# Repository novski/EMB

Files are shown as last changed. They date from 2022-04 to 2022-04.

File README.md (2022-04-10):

# EMB

Embedded-Rack is a multi SoC Powersupply with i2c connections.
It can be used to power up to 13 Raspberry Pi's and
 one Microcontroller to monitor Powerconsumption in Rackcase.

## How to

- Get a 19 inch DIN Rack similar to this from [schroff](https://schroff.nvent.com/products/19-subracks).

- Create a Backcover like in the drawing of /powersupply 
accordingly to your powersupply. I use this [MeanWell RSP-200-5](https://www.meanwell.com/productPdf.aspx?i=437)

- Connect a Poweroutlet (with fuse) and solder it to the 
psu and the psu to the backplane with carefully chosen cable 
diameter regarding your psu. 

- Get some Backplane connectors with 24x2.54mm pinn's 
like this from [aliex](https://de.aliexpress.com/wholesale?catId=0&initiative_id=SB_20220409111809&SearchText=pcb+edge+connector).

- Solder some connectors to a daughter-card and push your SoC 
on it.
pi: [mouser](http://ch.mouser.com/Search/ProductDetail.aspx?R=M20-6102045virtualkey57420000virtualkey855-M20-6102045)

- Stick the daughter-board in to the backplane.

## Powermeasureing

The i2c connection between all SoC's can be used as plane 
communication while adding an TI INA219 can be interessting 
to measure power over a board separate. Check the adafruit 
repo's for software and the schematic for parts.

## Impressions

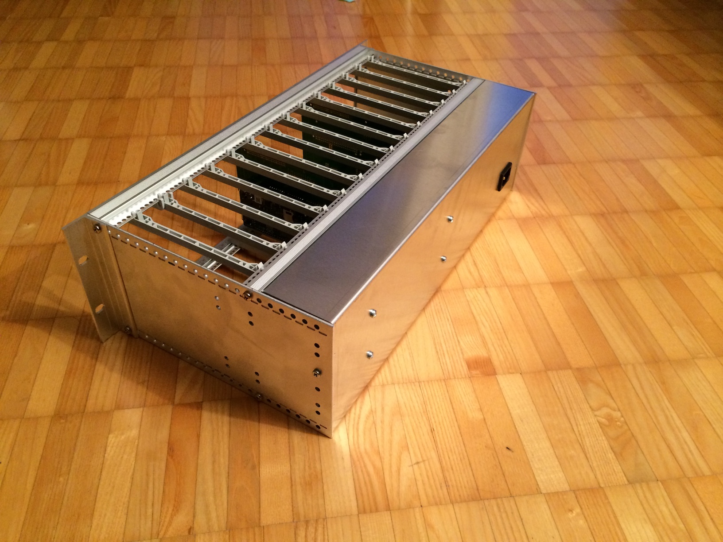
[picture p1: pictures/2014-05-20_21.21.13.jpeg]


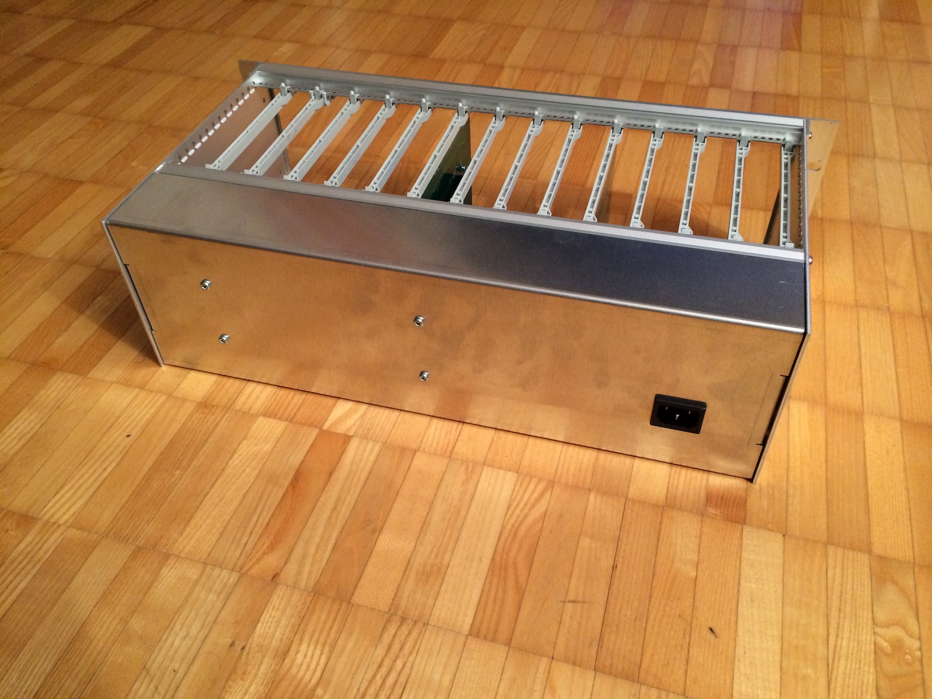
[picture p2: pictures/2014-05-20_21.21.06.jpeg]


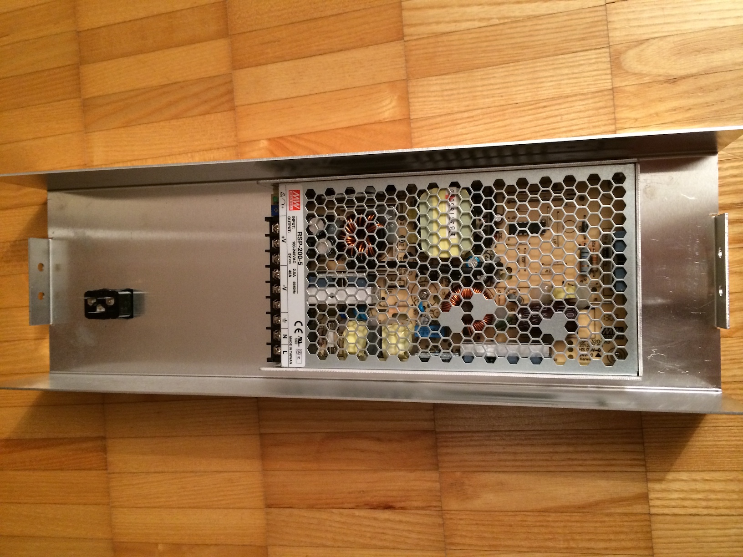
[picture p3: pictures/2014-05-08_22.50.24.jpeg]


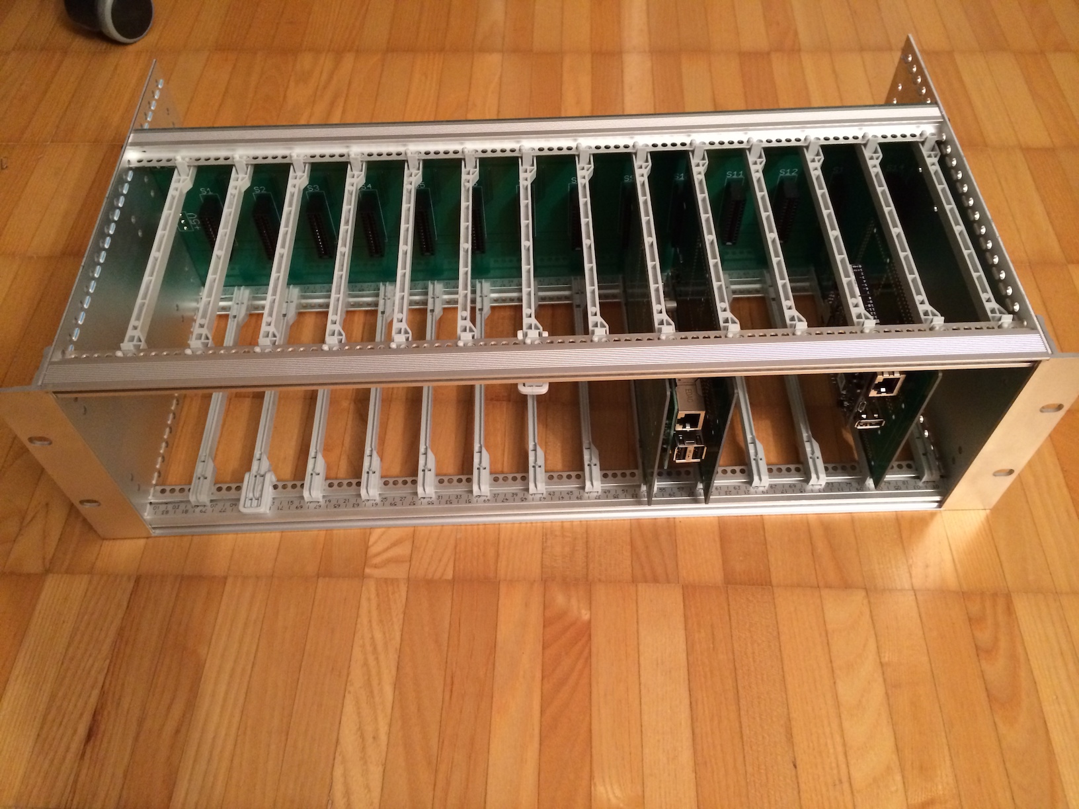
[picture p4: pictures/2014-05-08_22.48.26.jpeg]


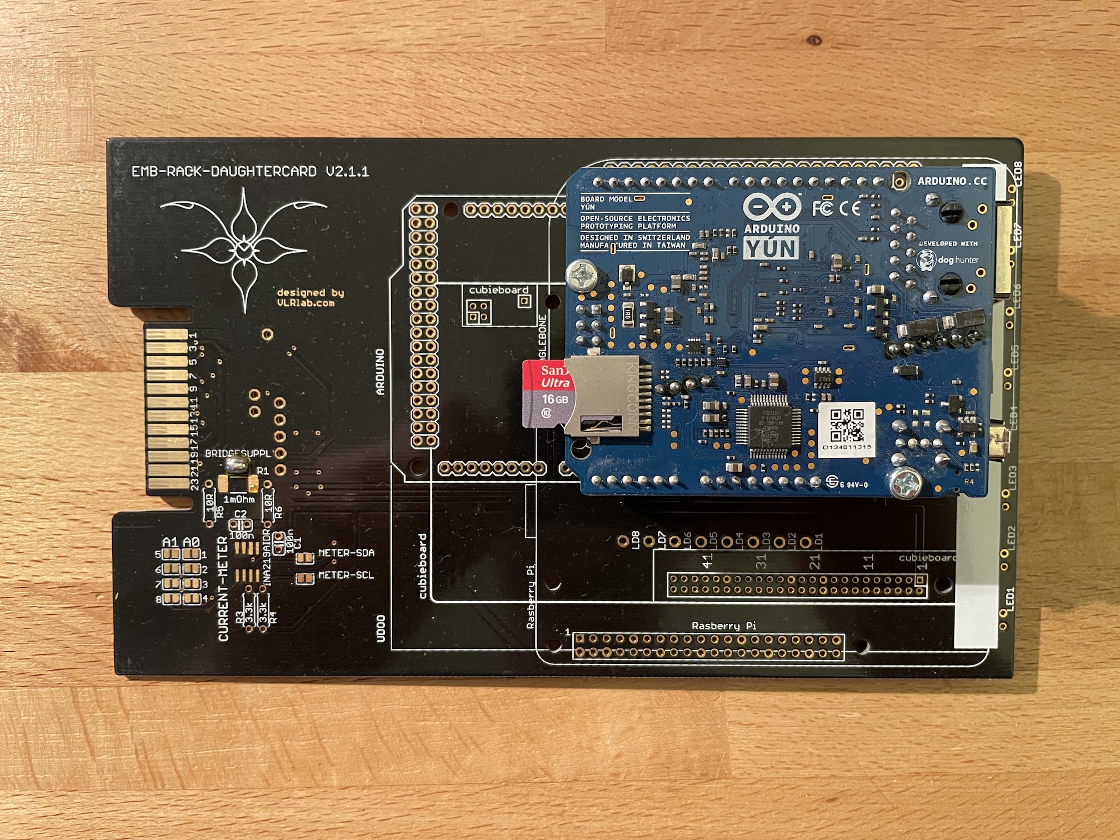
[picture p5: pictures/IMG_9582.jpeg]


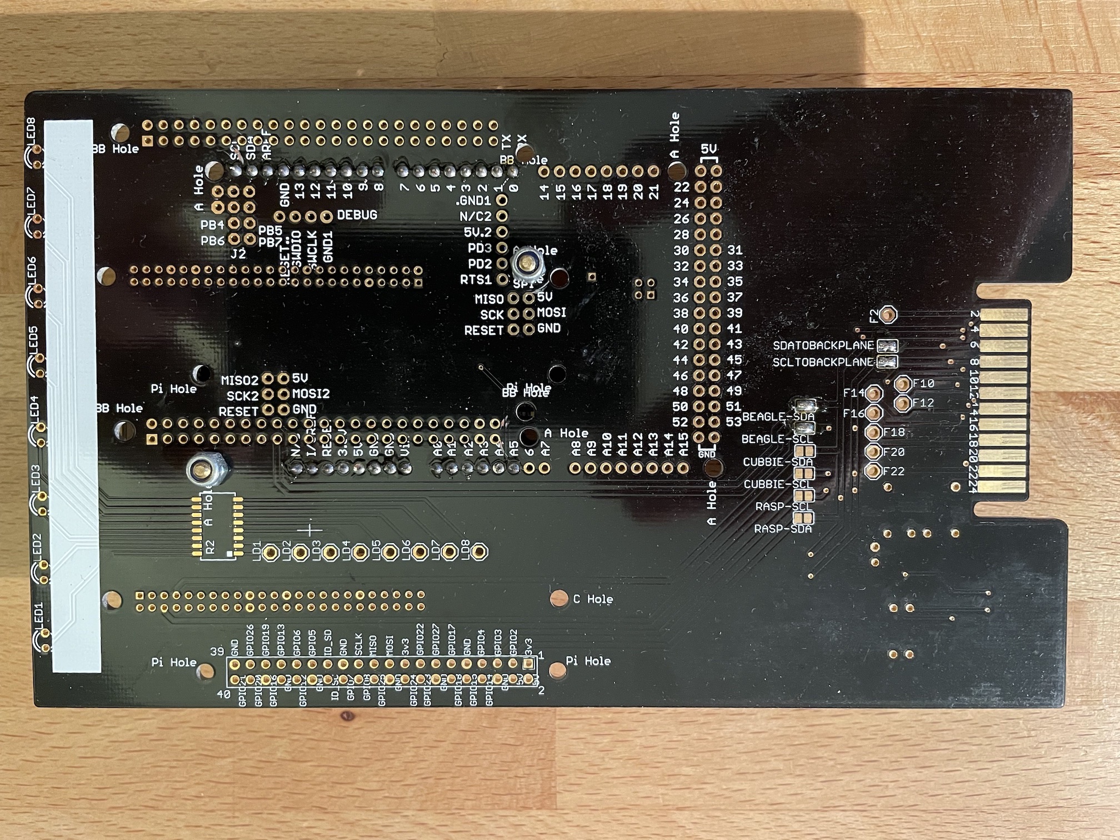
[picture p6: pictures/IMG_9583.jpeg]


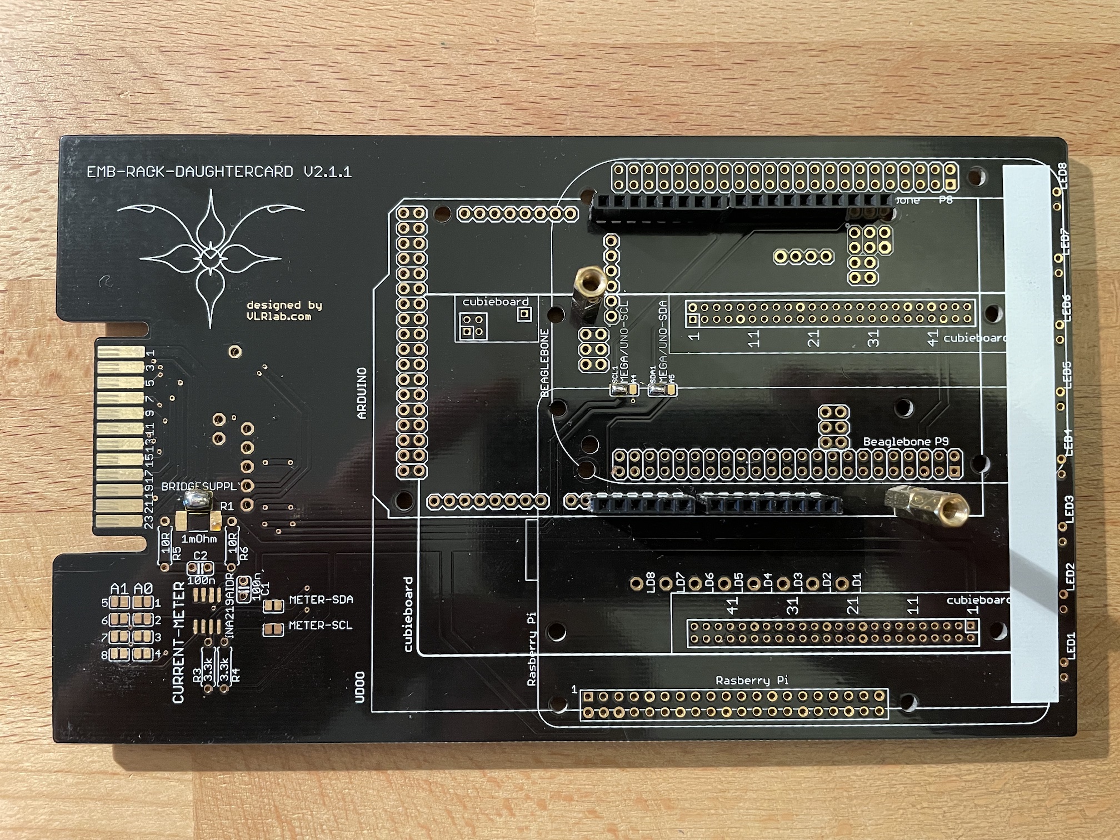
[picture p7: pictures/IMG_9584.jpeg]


## Disclaimer

All granted for free as in speech, without waranty.
(means that you can use, modify, share, sell if you like. 
But don't try to sue me for mistakes you do yourself.)
Be carefull with Power and re-calculate all wires according 
to your needs.

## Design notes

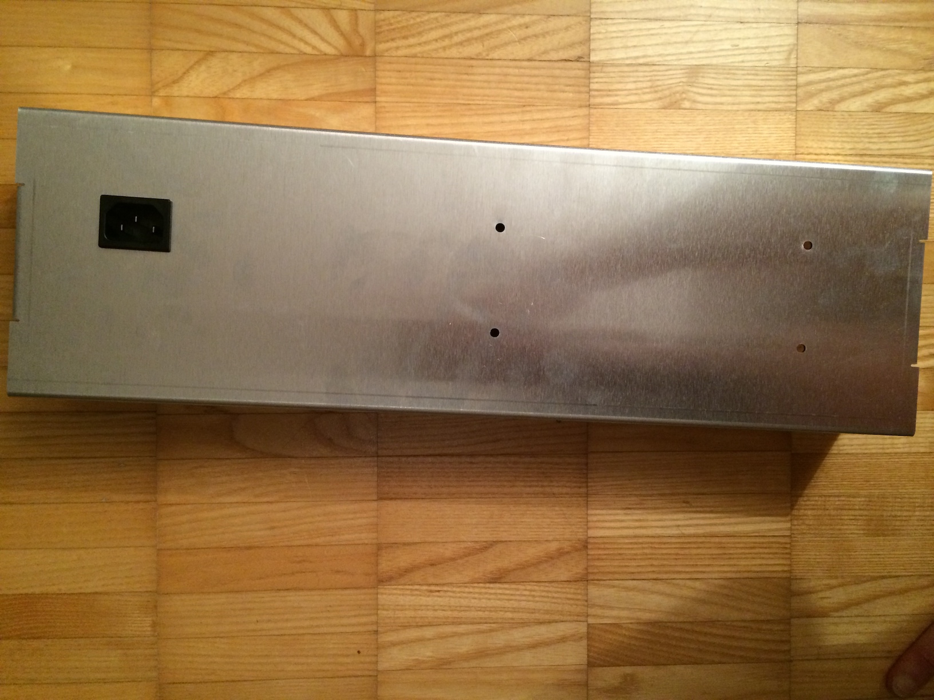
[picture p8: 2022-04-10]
pictures/2014-05-08_22.50.40.jpeg

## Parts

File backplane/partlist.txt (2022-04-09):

Partlist

Exported from 13+1 Port-Backplane.sch at 09.04.22 21:37

EAGLE Version 7.7.0 Copyright (c) 1988-2016 CadSoft

Assembly variant: 

Part     Value          Device       Package               Library    Sheet

S1       EDGECON-24P    EDGECON-24P  LEDSEE-BOARDCONN24PIN Ledsee     1
S2       EDGECON-24P    EDGECON-24P  LEDSEE-BOARDCONN24PIN Ledsee     1
S3       EDGECON-24P    EDGECON-24P  LEDSEE-BOARDCONN24PIN Ledsee     1
S4       EDGECON-24P    EDGECON-24P  LEDSEE-BOARDCONN24PIN Ledsee     1
S5       EDGECON-24P    EDGECON-24P  LEDSEE-BOARDCONN24PIN Ledsee     1
S6       EDGECON-24P    EDGECON-24P  LEDSEE-BOARDCONN24PIN Ledsee     1
S7       EDGECON-24P    EDGECON-24P  LEDSEE-BOARDCONN24PIN Ledsee     1
S8       EDGECON-24P    EDGECON-24P  LEDSEE-BOARDCONN24PIN Ledsee     1
S9       EDGECON-24P    EDGECON-24P  LEDSEE-BOARDCONN24PIN Ledsee     1
S10      EDGECON-24P    EDGECON-24P  LEDSEE-BOARDCONN24PIN Ledsee     1
S11      EDGECON-24P    EDGECON-24P  LEDSEE-BOARDCONN24PIN Ledsee     1
S12      EDGECON-24P    EDGECON-24P  LEDSEE-BOARDCONN24PIN Ledsee     1
S13      EDGECON-24P    EDGECON-24P  LEDSEE-BOARDCONN24PIN Ledsee     1
S14      EDGECON-24P    EDGECON-24P  LEDSEE-BOARDCONN24PIN Ledsee     1
U$6      SOLPAD-1,6MM   SOLPAD-1,6MM SOLDERPAD1.5MM        holes_Ivan 1
U$7      SOLPAD-1,6MM   SOLPAD-1,6MM SOLDERPAD1.5MM        holes_Ivan 1
U$8      SOLPAD-1,6MM   SOLPAD-1,6MM SOLDERPAD1.5MM        holes_Ivan 1
U$9      SOLPAD-1,6MM   SOLPAD-1,6MM SOLDERPAD1.5MM        holes_Ivan 1
U$10     SOLPAD-1,6MM   SOLPAD-1,6MM SOLDERPAD1.5MM        holes_Ivan 1
U$11     SOLPAD-1,6MM   SOLPAD-1,6MM SOLDERPAD1.5MM        holes_Ivan 1

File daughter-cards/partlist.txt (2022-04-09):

Partlist

Exported from UniversalRackcard.sch at 09.04.22 21:35

EAGLE Version 7.7.0 Copyright (c) 1988-2016 CadSoft

Assembly variant: 

Part           Value            Device           Package         Library               Sheet

1              GND              SJ               SJ              jumper                1
2              VDD              SJ               SJ              jumper                1
3              SDA              SJ               SJ              jumper                1
4              SCL              SJ               SJ              jumper                1
5              GND              SJ               SJ              jumper                1
6              VDD              SJ               SJ              jumper                1
7              SDA              SJ               SJ              jumper                1
8              SCL              SJ               SJ              jumper                1
BEAGLE-SCL                      SJ               SJ              jumper                1
BEAGLE-SDA                      SJ               SJ              jumper                1
BRIDGESUPPLY                    SJW              SJW             jumper                1
C1             100n             C-EU025-024X044  C025-024X044    rcl                   1
C2             100n             C-EU025-024X044  C025-024X044    rcl                   1
CUBBIE-SCL                      SJ               SJ              jumper                1
CUBBIE-SDA                      SJ               SJ              jumper                1
CURRENT-METER  INA219AIDR       INA219AIDR       SO-08           texas                 1
F2             SE13             SE13             SE13            solpad                1
F10            SE13             SE13             SE13            solpad                1
F12            SE13             SE13             SE13            solpad                1
F14            SE13             SE13             SE13            solpad                1
F16            SE13             SE13             SE13            solpad                1
F18            SE13             SE13             SE13            solpad                1
F20            SE13             SE13             SE13            solpad                1
F22            SE13             SE13             SE13            solpad                1
LD1            SE13             SE13             SE13            solpad                1
LD2            SE13             SE13             SE13            solpad                1
LD3            SE13             SE13             SE13            solpad                1
LD4            SE13             SE13             SE13            solpad                1
LD5            SE13             SE13             SE13            solpad                1
LD6            SE13             SE13             SE13            solpad                1
LD7            SE13             SE13             SE13            solpad                1
LD8            SE13             SE13             SE13            solpad                1
LED1                            LED3MM           LED3MM          led                   1
LED2                            LED3MM           LED3MM          led                   1
LED3                            LED3MM           LED3MM          led                   1
LED4                            LED3MM           LED3MM          led                   1
LED5                            LED3MM           LED3MM          led                   1
LED6                            LED3MM           LED3MM          led                   1
LED7                            LED3MM           LED3MM          led                   1
LED8                            LED3MM           LED3MM          led                   1
MEGA/UNO-SCL                    SJ2W             SJ_2            jumper                1
MEGA/UNO-SDA                    SJ2W             SJ_2            jumper                1
METER-SCL                       SJ               SJ              jumper                1
METER-SDA                       SJ               SJ              jumper                1
R1             1mOhm            R-EU_R2512       R2512           resistor              1
R2                              4816P-1SOIC16W   SOIC16W         Bourns Resistor Array 1
R3             3.3k             R-EU_0207/7      0207/7          rcl                   1
R4             3.3k             R-EU_0207/7      0207/7          rcl                   1
R5             10R              R-EU_0207/7      0207/7          rcl                   1
R6             10R              R-EU_0207/7      0207/7          rcl                   1
RASP-SCL                        SJ               SJ              jumper                1
RASP-SDA                        SJ               SJ              jumper                1
SCLTOBACKPLANE                  SJ               SJ              jumper                1
SDATOBACKPLANE                  SJ               SJ              jumper                1
U$2            VLR_EUROCARD     VLR_EUROCARD     VLR_EUROCARD    Frames_VLR            1
U$4            ARDUINO_ALL      ARDUINO_ALL      ALL             Arduino               1
U$5            CUBIEBOARD       CUBIEBOARD       CUBIEBOARD      Cubie                 1
U$6            BEAGLEBONE-BLACK BEAGLEBONE-BLACK BEAGLEBONE      beaglebone            1
U$7            RASPBERRY-PI_B+  RASPBERRY-PI_B+  RASPBERRY-PI_B+ RaspberryPi           1

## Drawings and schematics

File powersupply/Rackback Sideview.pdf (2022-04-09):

B

C

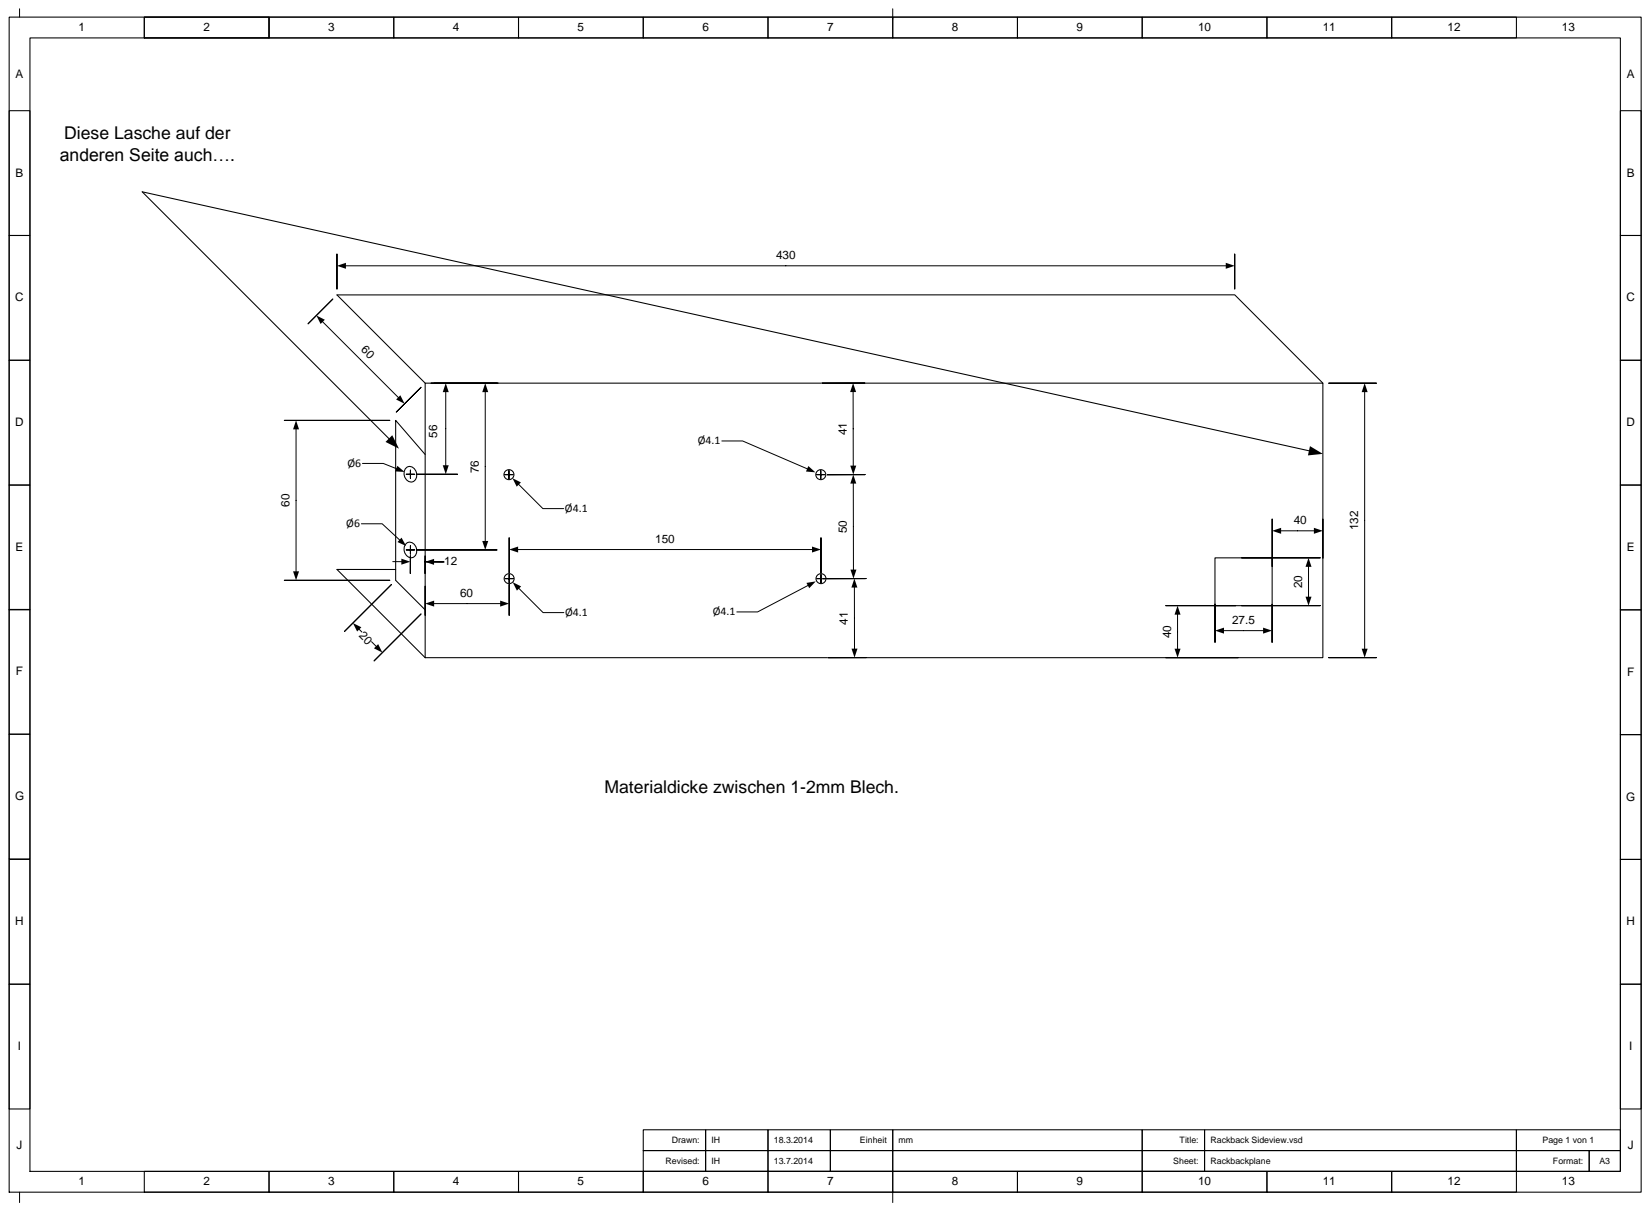
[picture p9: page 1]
Rackback Sideview.vsd Rackbackplane; Format:; A3 Title:; Sheet: Drawn:; Page 1 von 1 Revised:; Einheit

Diese Lasche auf der
anderen Seite auch….

Materialdicke zwischen 1-2mm Blech.

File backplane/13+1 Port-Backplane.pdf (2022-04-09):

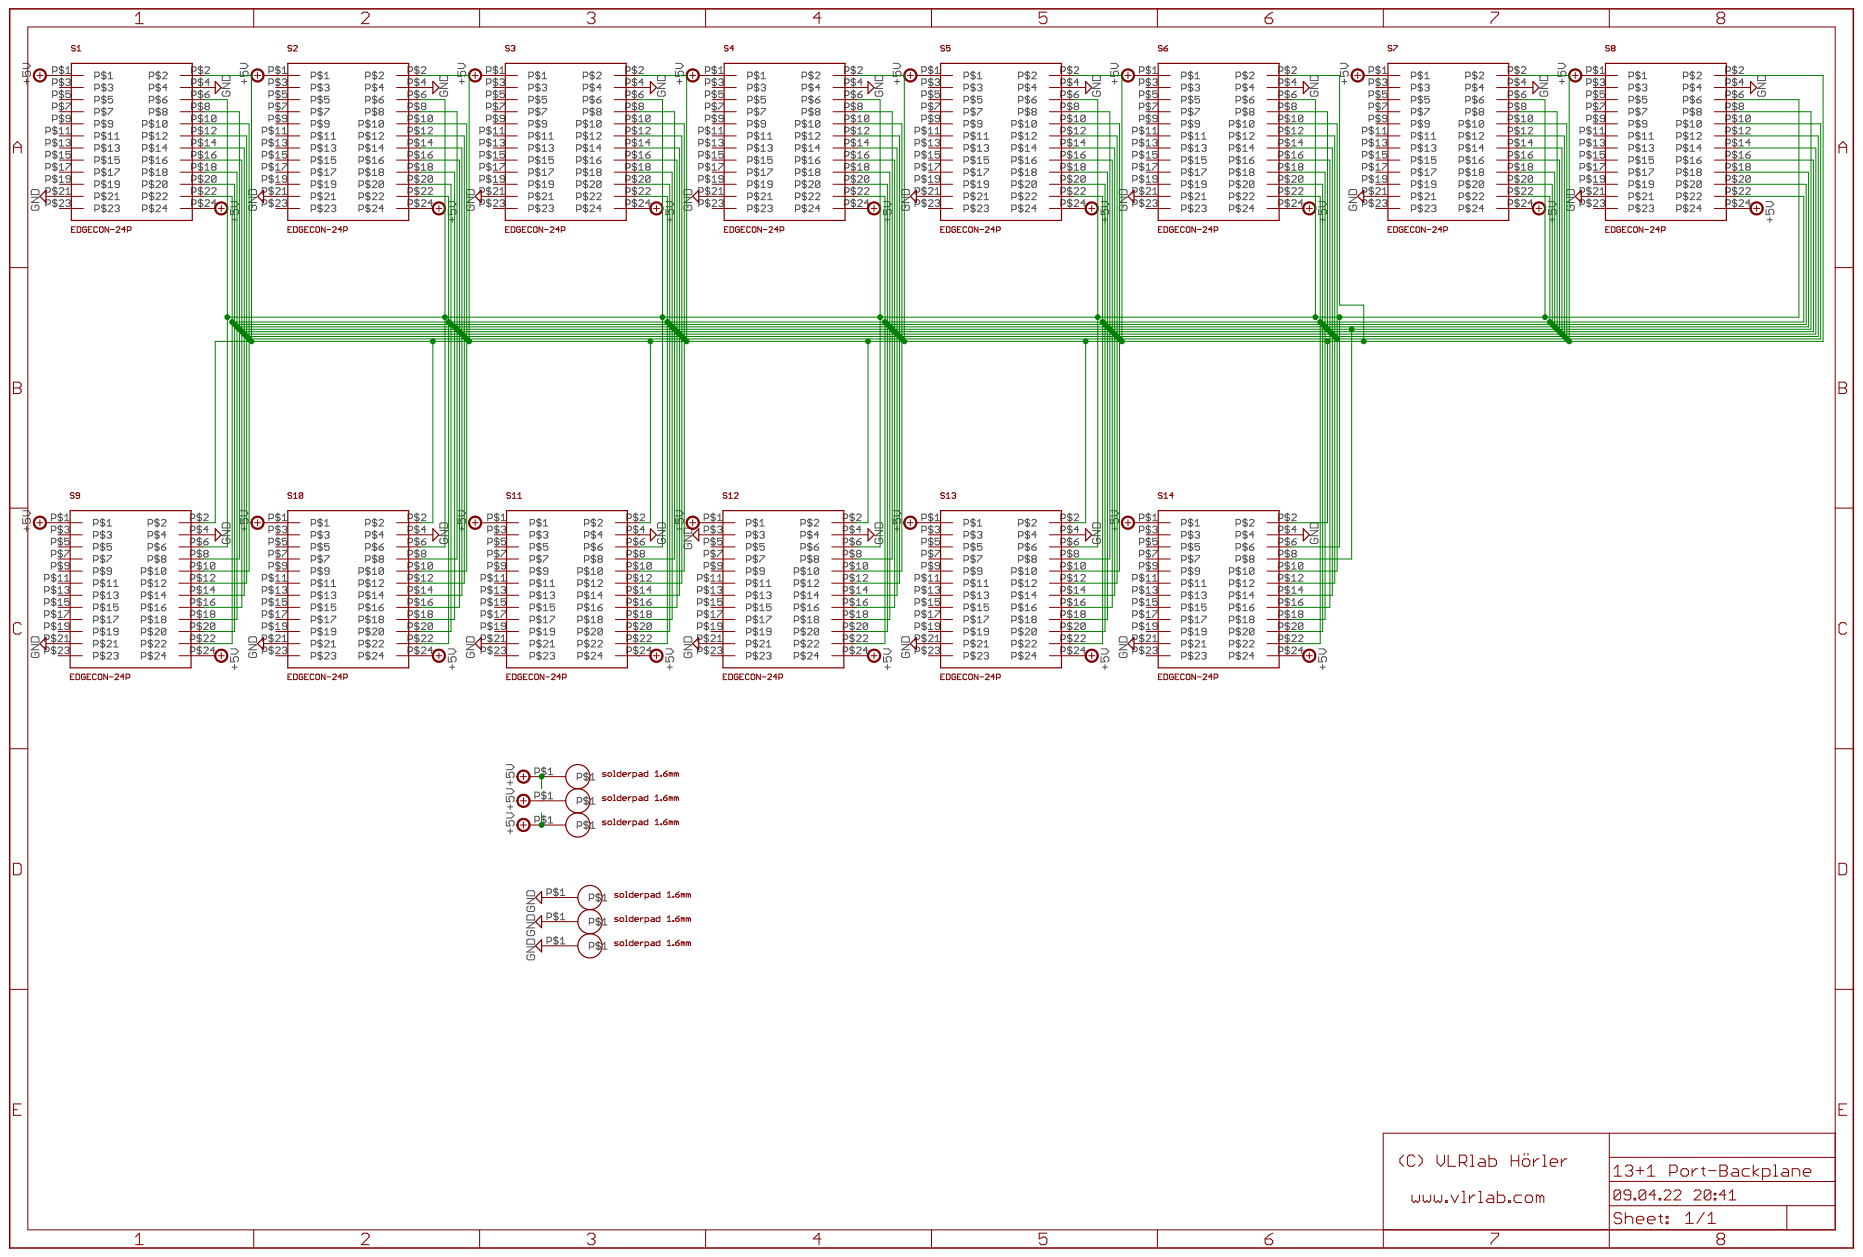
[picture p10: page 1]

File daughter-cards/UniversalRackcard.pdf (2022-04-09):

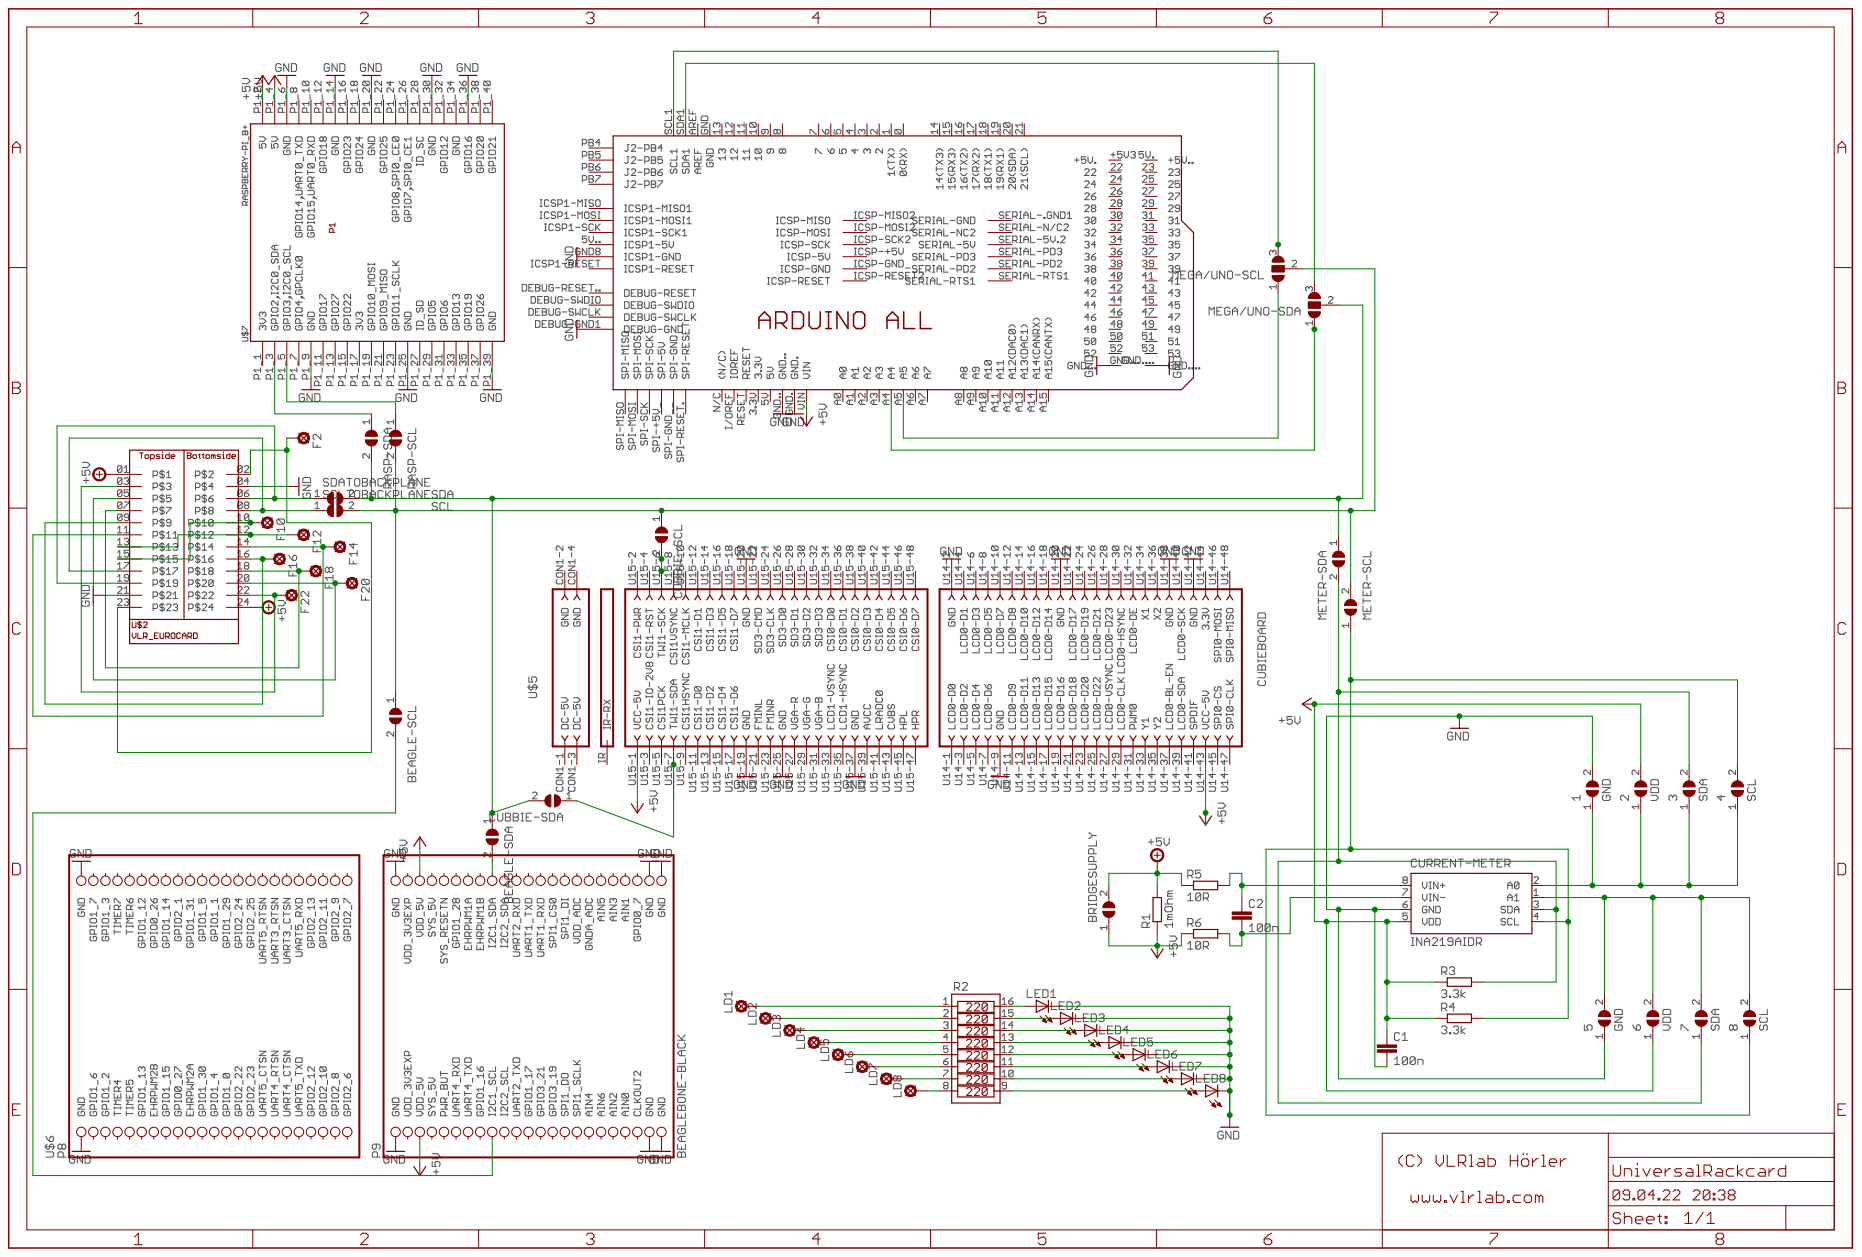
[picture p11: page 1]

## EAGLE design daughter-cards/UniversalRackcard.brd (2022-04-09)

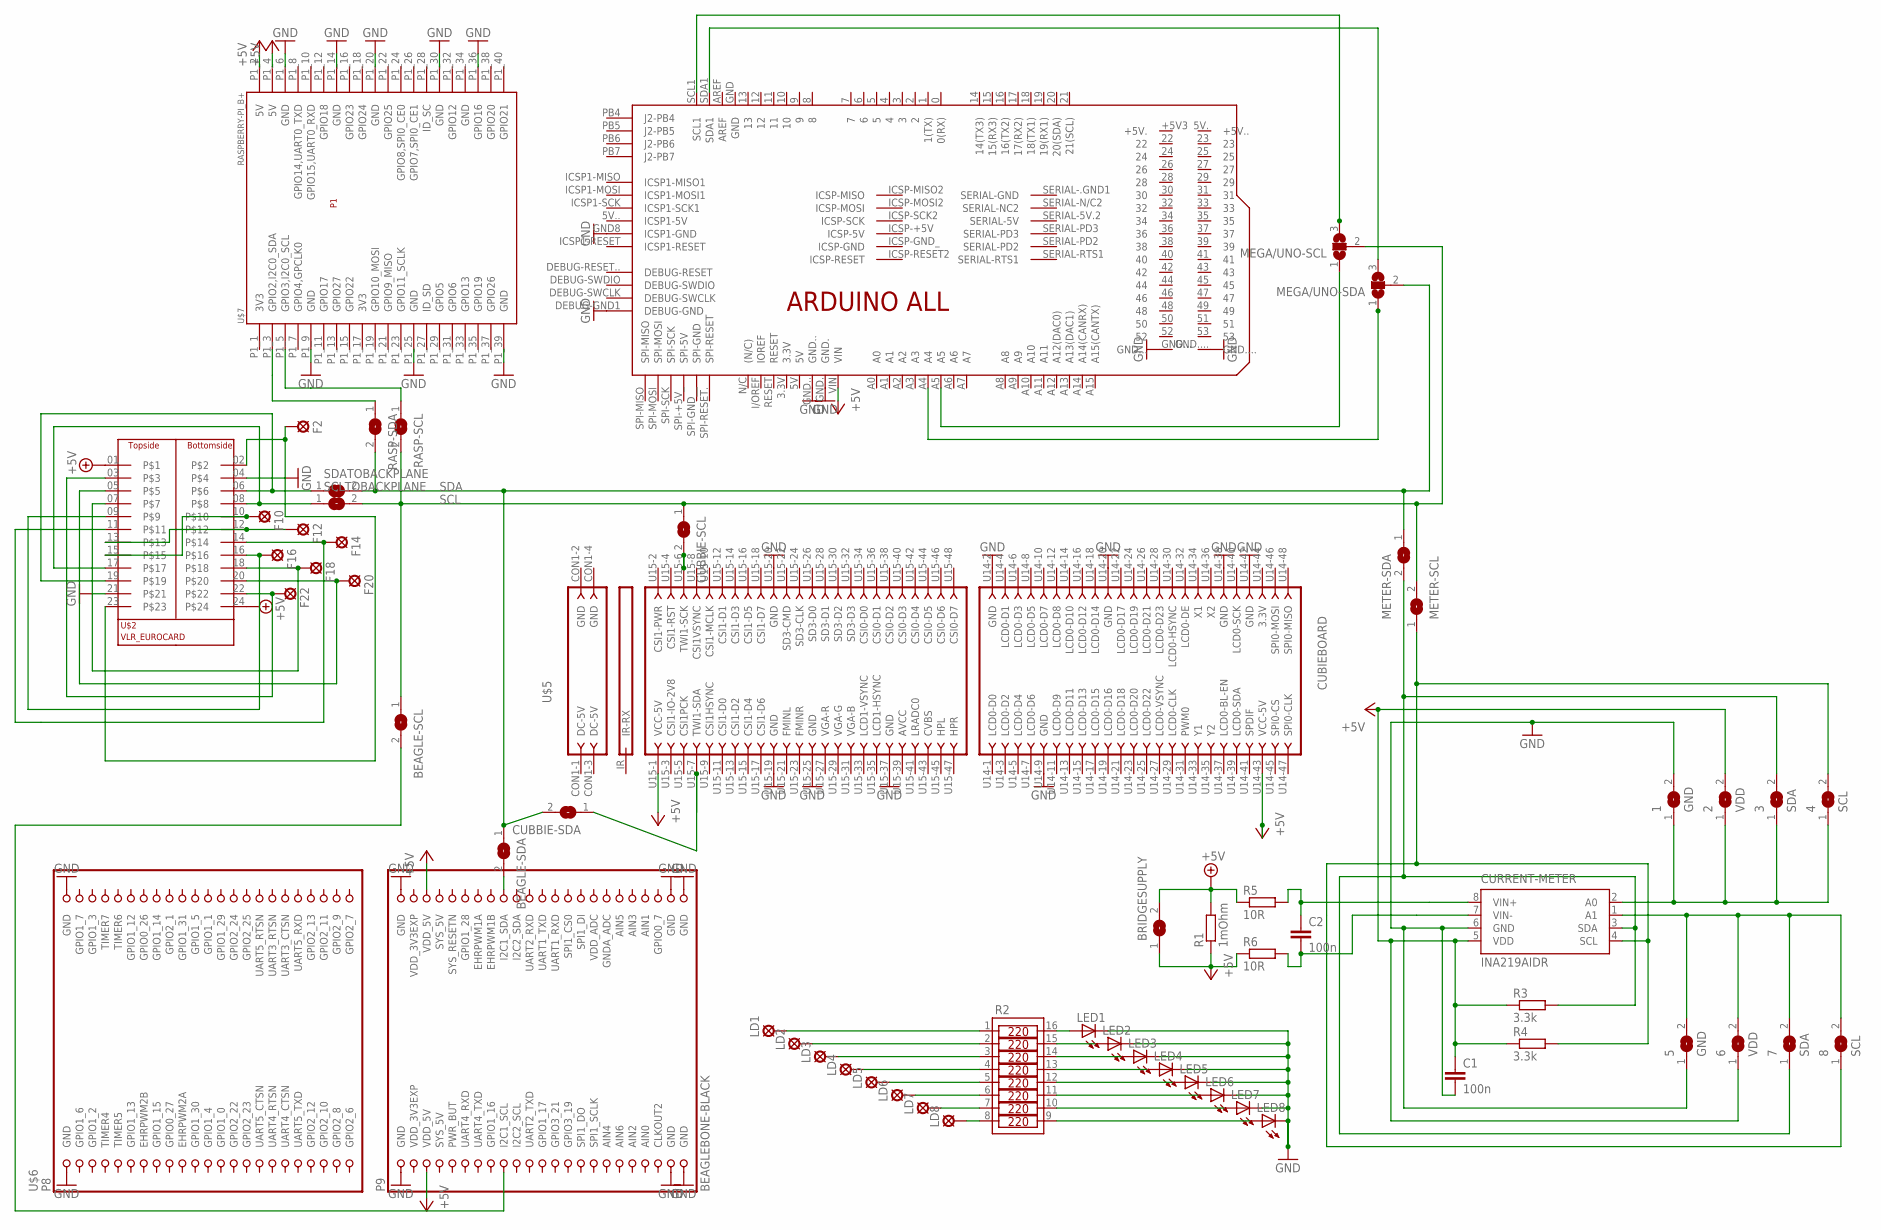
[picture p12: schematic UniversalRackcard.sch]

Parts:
1, 5: GND; SJ
2, 6: VDD; SJ
3, 7: SDA; SJ
4, 8: SCL; SJ
BEAGLE-SCL: SJ
BEAGLE-SDA: SJ
BRIDGESUPPLY: SJW
C1, C2: 100n; C025-024X044
CUBBIE-SCL: SJ
CUBBIE-SDA: SJ
CURRENT-METER: INA219AIDR; SO-08
F2, F10, F12, F14, F16, F18, F20, F22: SE13
LD1, LD2, LD3, LD4, LD5, LD6, LD7, LD8: SE13
LED1, LED2, LED3, LED4, LED5, LED6, LED7, LED8: LED3MM
MEGA/UNO-SCL: SJ2W; SJ_2
MEGA/UNO-SDA: SJ2W; SJ_2
METER-SCL: SJ
METER-SDA: SJ
R1: 1mOhm; R2512
R2: 4816P-1SOIC16W; SOIC16W
R3, R4: 3.3k; 0207/7
R5, R6: 10R; 0207/7
RASP-SCL: SJ
RASP-SDA: SJ
SCLTOBACKPLANE: SJ
SDATOBACKPLANE: SJ
U$2: VLR_EUROCARD
U$4: ARDUINO_ALL; ALL
U$5: CUBIEBOARD
U$6: BEAGLEBONE-BLACK; BEAGLEBONE
U$7: RASPBERRY-PI_B+

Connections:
+5V: 2.2, 6.1, BRIDGESUPPLY.1, C1.1, CURRENT-METER.5 (VDD), R1.1, R3.1, R4.1, R6.1, U$4.VIN, U$5.U14-43 (VCC-5V), U$5.U15-1 (VCC-5V), U$6.51 (VDD_5V), U$6.52 (VDD_5V), U$7.P1_2 (5V), U$7.P1_4 (5V)
A0: 1.1, 2.1, 3.1, 4.1, CURRENT-METER.2 (A0)
A1: 5.2, 6.2, 7.2, 8.2, CURRENT-METER.1 (A1)
AIN0: U$6.85 (AIN0)
GND: 1.2, 5.1, C1.2, CURRENT-METER.6 (GND), LED1.K (C), LED2.K (C), LED3.K (C), LED4.K (C), LED5.K (C), LED6.K (C), LED7.K (C), LED8.K (C), U$2.04, U$2.21, U$4.DEBUG-GND1 (DEBUG-GND), U$4.GND8 (ICSP1-GND), U$4.GND., U$4.GND.., U$5.U14-2 (GND), U$5.U14-9 (GND), U$5.U14-20 (GND), U$5.U14-38 (GND), U$5.U14-42 (GND), U$5.U15-19 (GND), U$5.U15-20 (GND), U$5.U15-25 (GND), U$5.U15-37 (GND), U$6.47 (GND), U$6.48 (GND), U$6.89 (GND), U$6.90 (GND), U$6.91 (GND), U$6.92 (GND), U$6.P8-1 (GND), U$6.P8-2 (GND), U$7.P1_6 (GND), U$7.P1_9 (GND), U$7.P1_14 (GND), U$7.P1_20 (GND), U$7.P1_25 (GND), U$7.P1_30 (GND), U$7.P1_36 (GPIO16), U$7.P1_39 (GND)
unnamed: MEGA/UNO-SDA.1, U$4.A4
unnamed: MEGA/UNO-SCL.1, U$4.A5
unnamed: MEGA/UNO-SCL.3, U$4.SCL1
unnamed: MEGA/UNO-SDA.3, U$4.SDA1
unnamed: 3.2, 7.1, CURRENT-METER.3 (SDA), METER-SDA.2, R3.2
unnamed: 4.2, 8.1, CURRENT-METER.4 (SCL), METER-SCL.1, R4.2
unnamed: LD1.MP, R2.1
unnamed: LD2.MP, R2.2
unnamed: LD3.MP, R2.3
unnamed: SDATOBACKPLANE.1, U$2.06, U$2.19
unnamed: SCLTOBACKPLANE.1, U$2.08, U$2.17
unnamed: LD4.MP, R2.4
unnamed: LD5.MP, R2.5
unnamed: LD6.MP, R2.6
unnamed: LD7.MP, R2.7
unnamed: LD8.MP, R2.8
unnamed: LED1.A, R2.16
unnamed: LED2.A, R2.15
unnamed: LED3.A, R2.14
unnamed: LED4.A, R2.13
unnamed: LED6.A, R2.11
unnamed: LED5.A, R2.12
unnamed: LED7.A, R2.10
unnamed: LED8.A, R2.9
unnamed: CUBBIE-SDA.1, U$5.U15-7 (TWI1-SDA)
unnamed: BEAGLE-SDA.2, U$6.64 (I2C1_SDA)
unnamed: BEAGLE-SCL.2, U$6.63 (I2C1_SCL)
unnamed: CUBBIE-SCL.2, U$5.U15-6 (TWI1-SCK)
unnamed: RASP-SCL.1, U$7.P1_5 (GPIO3,I2C0_SCL)
unnamed: RASP-SDA.1, U$7.P1_3 (GPIO2,I2C0_SDA)
unnamed: F2.MP, U$2.02, U$2.23
unnamed: F10.MP, U$2.10, U$2.15
unnamed: F12.MP, U$2.12, U$2.13
unnamed: F14.MP, U$2.11, U$2.14
unnamed: F16.MP, U$2.09, U$2.16
unnamed: F18.MP, U$2.07, U$2.18
unnamed: F20.MP, U$2.05, U$2.20
unnamed: F22.MP, U$2.03, U$2.22
PRIM+5V: BRIDGESUPPLY.2, R1.2, R5.1, U$2.01, U$2.24
SCL: BEAGLE-SCL.1, CUBBIE-SCL.1, MEGA/UNO-SCL.2, METER-SCL.2, RASP-SCL.2, SCLTOBACKPLANE.2
SDA: BEAGLE-SDA.1, CUBBIE-SDA.2, MEGA/UNO-SDA.2, METER-SDA.1, RASP-SDA.2, SDATOBACKPLANE.2
SYS_5V: U$6.53 (SYS_5V)
VDD_3V3EXP: U$6.49 (VDD_3V3EXP), U$6.50 (VDD_3V3EXP)
VIN+: C2.1, CURRENT-METER.8 (VIN+), R5.2
VIN-: C2.2, CURRENT-METER.7 (VIN-), R6.2

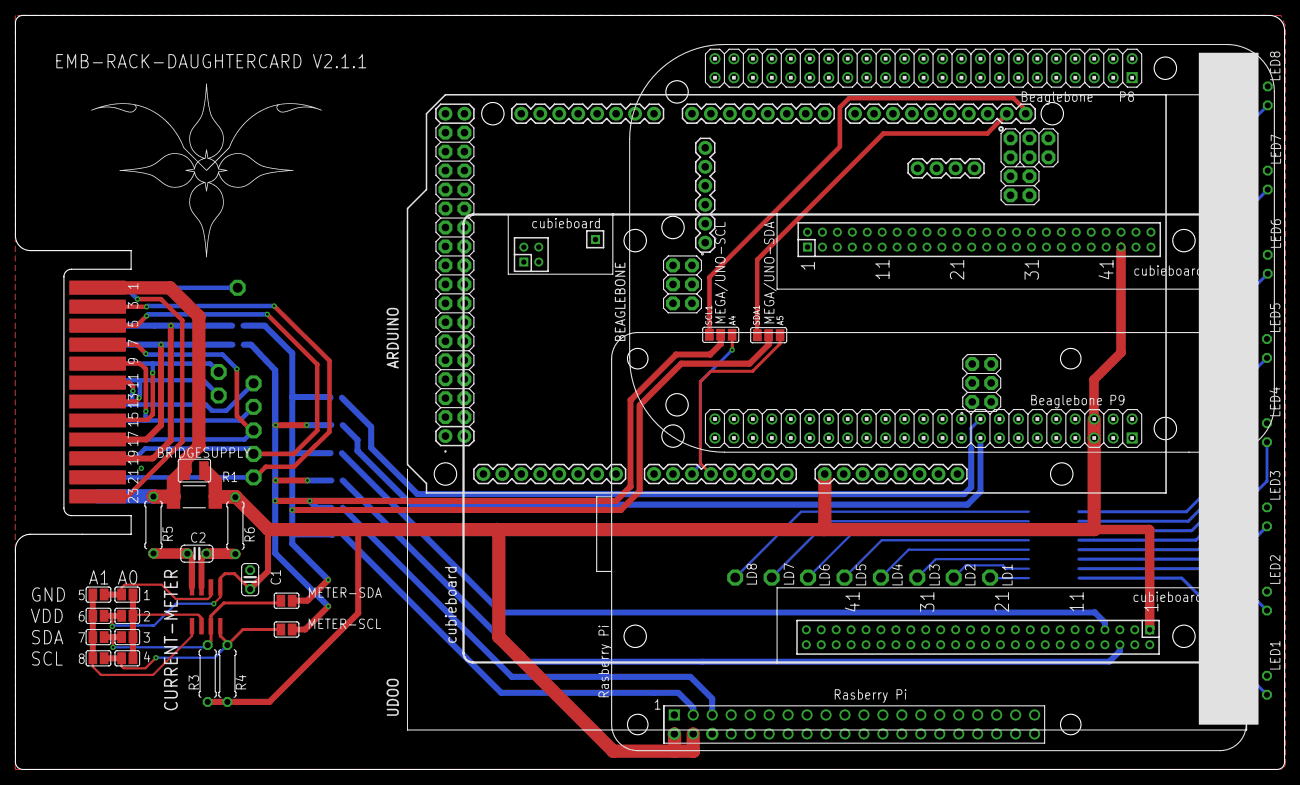
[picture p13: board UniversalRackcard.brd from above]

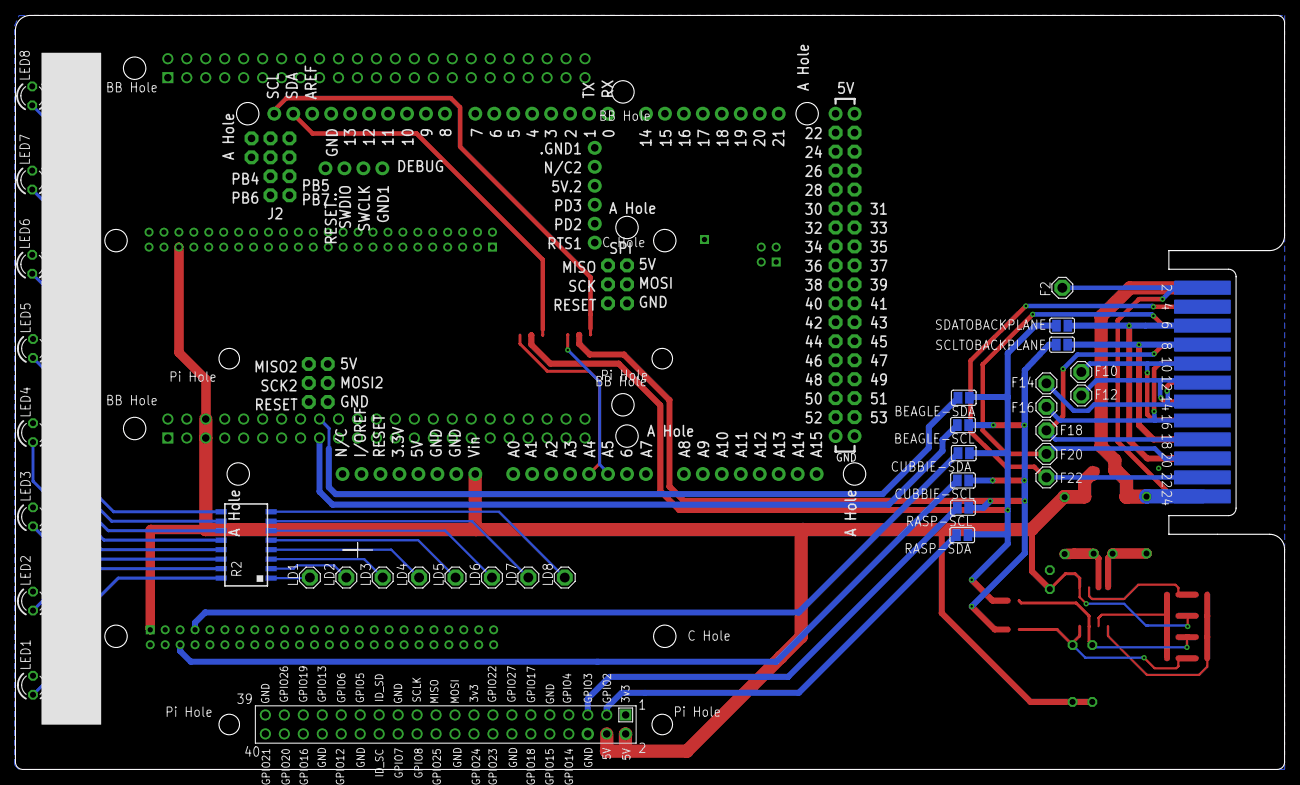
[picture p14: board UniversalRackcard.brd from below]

Board: 2 copper layers, 170.0 x 101.0 mm, 61 parts (36 on the bottom side), 48 nets.

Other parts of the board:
U$3, U$8: VLRLAB

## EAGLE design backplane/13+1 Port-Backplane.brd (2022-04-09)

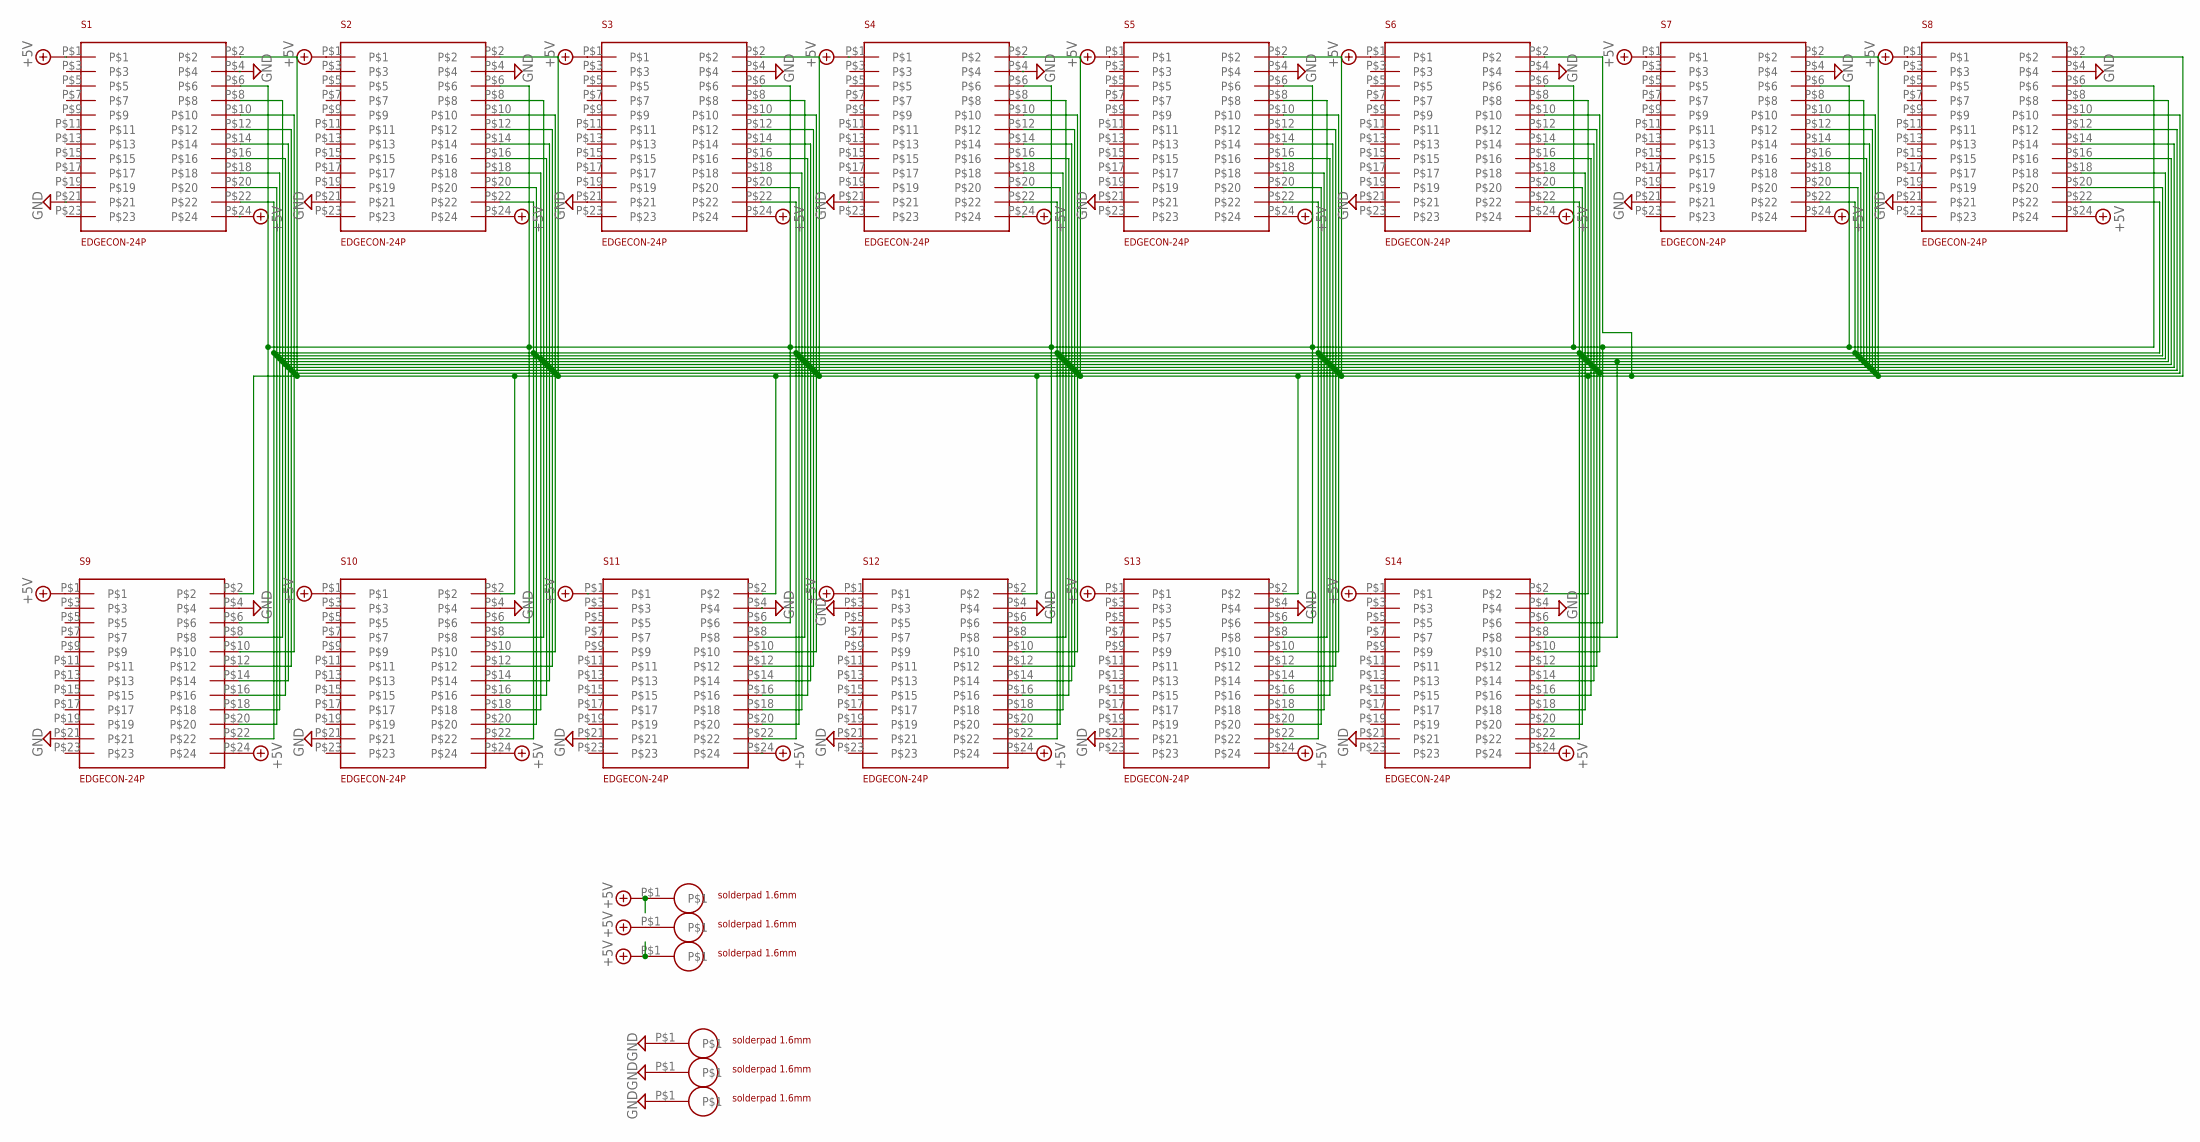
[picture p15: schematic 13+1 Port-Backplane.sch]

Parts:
S1, S2, S3, S4, S5, S6, S7, S8, S9, S10, S11, S12, S13, S14: EDGECON-24P; LEDSEE-BOARDCONN24PIN
U$6, U$7, U$8, U$9, U$10, U$11: SOLPAD-1,6MM; SOLDERPAD1.5MM

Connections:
+5V: S1.P$1, S1.P$24, S2.P$1, S2.P$24, S3.P$1, S3.P$24, S4.P$1, S4.P$24, S5.P$1, S5.P$24, S6.P$1, S6.P$24, S7.P$1, S7.P$24, S8.P$1, S8.P$24, S9.P$1, S9.P$24, S10.P$1, S10.P$24, S11.P$1, S11.P$24, S12.P$1, S12.P$24, S13.P$1, S13.P$24, S14.P$1, S14.P$24, U$6.P$1, U$7.P$1, U$9.P$1
GND: S1.P$4, S1.P$21, S2.P$4, S2.P$21, S3.P$4, S3.P$21, S4.P$4, S4.P$21, S5.P$4, S5.P$21, S6.P$4, S6.P$21, S7.P$4, S7.P$21, S8.P$4, S8.P$21, S9.P$4, S9.P$21, S10.P$4, S10.P$21, S11.P$4, S11.P$21, S12.P$3, S12.P$4, S12.P$21, S13.P$4, S13.P$21, S14.P$4, S14.P$21, U$8.P$1, U$10.P$1, U$11.P$1
PIN2: S1.P$2, S2.P$2, S3.P$2, S4.P$2, S5.P$2, S6.P$2, S7.P$2, S8.P$2, S9.P$2, S10.P$2, S11.P$2, S12.P$2, S13.P$2, S14.P$2
PIN6: S1.P$6, S2.P$6, S3.P$6, S4.P$6, S5.P$6, S6.P$6, S7.P$6, S8.P$6, S9.P$6, S10.P$6, S11.P$6, S12.P$6, S13.P$6, S14.P$6
PIN8: S1.P$8, S2.P$8, S3.P$8, S4.P$8, S5.P$8, S6.P$8, S7.P$8, S8.P$8, S9.P$8, S10.P$8, S11.P$8, S12.P$8, S13.P$8, S14.P$8
PIN10: S1.P$10, S2.P$10, S3.P$10, S4.P$10, S5.P$10, S6.P$10, S7.P$10, S8.P$10, S9.P$10, S10.P$10, S11.P$10, S12.P$10, S13.P$10, S14.P$10
PIN12: S1.P$12, S2.P$12, S3.P$12, S4.P$12, S5.P$12, S6.P$12, S7.P$12, S8.P$12, S9.P$12, S10.P$12, S11.P$12, S12.P$12, S13.P$12, S14.P$12
PIN14: S1.P$14, S2.P$14, S3.P$14, S4.P$14, S5.P$14, S6.P$14, S7.P$14, S8.P$14, S9.P$14, S10.P$14, S11.P$14, S12.P$14, S13.P$14, S14.P$14
PIN16: S1.P$16, S2.P$16, S3.P$16, S4.P$16, S5.P$16, S6.P$16, S7.P$16, S8.P$16, S9.P$16, S10.P$16, S11.P$16, S12.P$16, S13.P$16, S14.P$16
PIN18: S1.P$18, S2.P$18, S3.P$18, S4.P$18, S5.P$18, S6.P$18, S7.P$18, S8.P$18, S9.P$18, S10.P$18, S11.P$18, S12.P$18, S13.P$18, S14.P$18
PIN20: S1.P$20, S2.P$20, S3.P$20, S4.P$20, S5.P$20, S6.P$20, S7.P$20, S8.P$20, S9.P$20, S10.P$20, S11.P$20, S12.P$20, S13.P$20, S14.P$20
PIN22: S1.P$22, S2.P$22, S3.P$22, S4.P$22, S5.P$22, S6.P$22, S7.P$22, S8.P$22, S9.P$22, S10.P$22, S11.P$22, S12.P$22, S13.P$22, S14.P$22

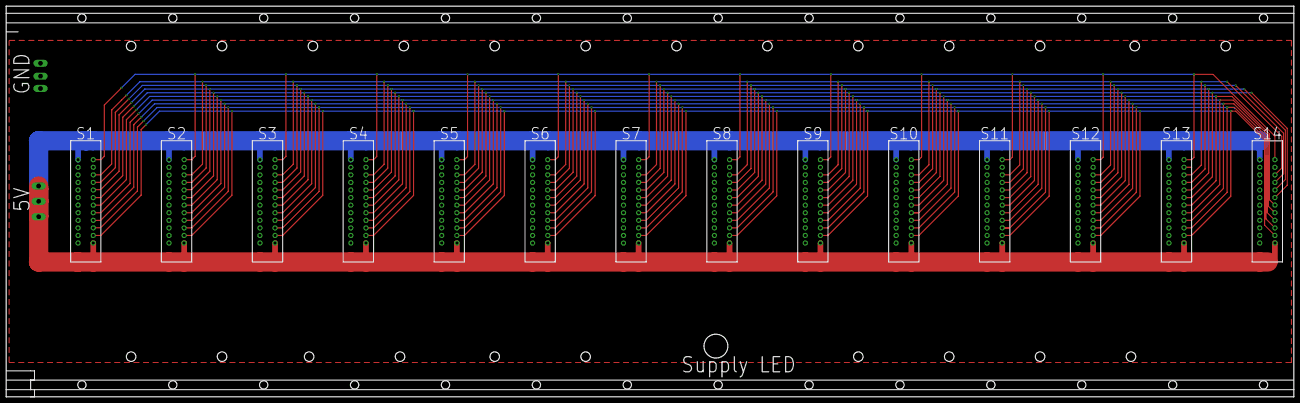
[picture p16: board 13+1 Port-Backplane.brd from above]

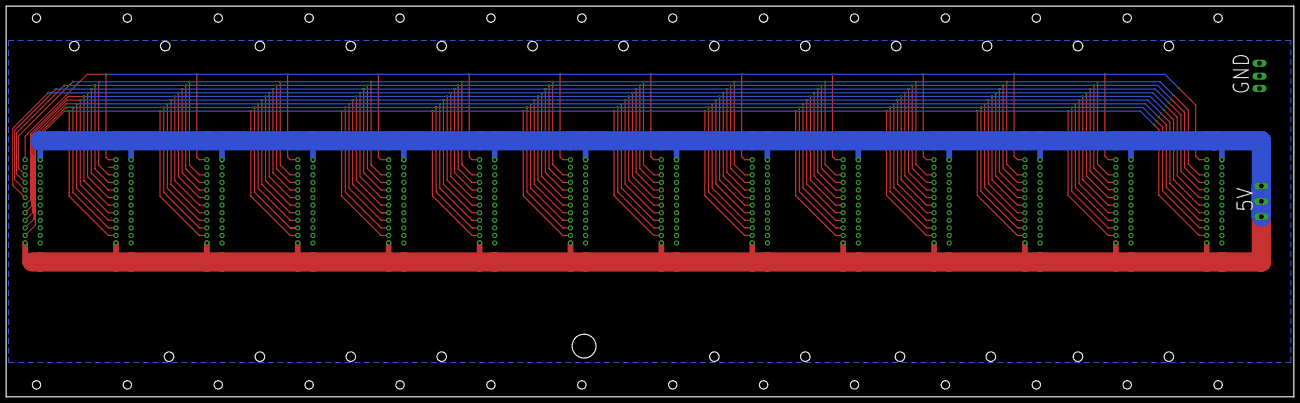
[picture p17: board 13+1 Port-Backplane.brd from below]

Board: 2 copper layers, 431.8 x 131.0 mm, 25 parts (2 on the bottom side), 12 nets.

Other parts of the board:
U$2: BAUGRUPPENTRAEGERBACKPLANEFULL@1
U$3, U$4: VLRLAB
U$5, U$12: BACKPLANE

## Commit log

2014-11-07 Added Daughterboard
    [UnicersalRackcard.brd, UnicersalRackcard.sch]
2022-04-09 add recent information
    [13+1 Port-Backplane.brd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]
